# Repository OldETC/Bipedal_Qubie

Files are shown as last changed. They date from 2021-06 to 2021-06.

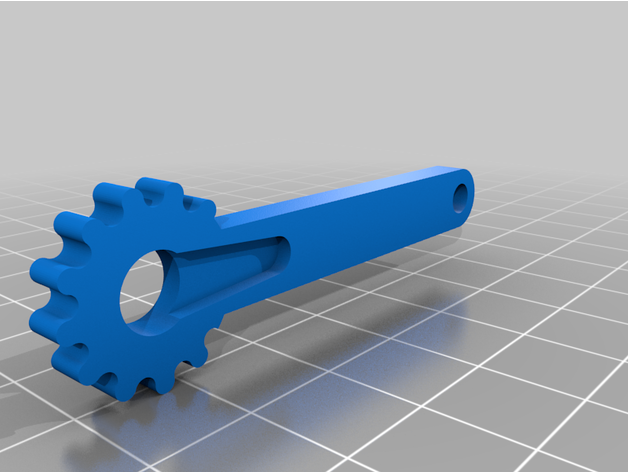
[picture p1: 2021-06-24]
PrintDesign/minigripper/minigripper/images/Servo_Connector_Gear.png

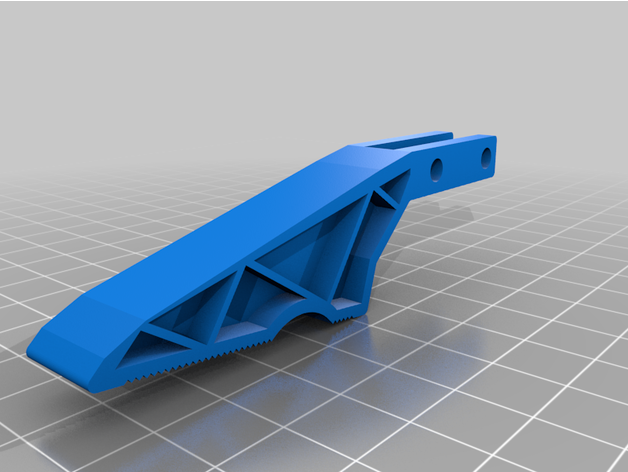
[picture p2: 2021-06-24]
PrintDesign/minigripper/temp/images/Claw.png

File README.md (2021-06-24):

# Bipedal_Qubie

20200904_standing

Prototype small (40" tall) humanoid robot
This robot is just for personal use, not commercial.  It is built from readily available hobby
electronics, hobby servos and the skeleton is 3D printed.  I have been working on it for quite a
while, but not accomplished much other than to get the basic robot built and standing on its
own.  I have gotten the  gazebo model complete, but not debugged or the driver code written yet.

The file include documentation for the electronics used, the servos, the OpenSCAD files for the skeleton, some documentation, and a bit of the test code for the robot.

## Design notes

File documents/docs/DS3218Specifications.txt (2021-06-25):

DS3218 specifications:
DS3218MG Servo can be commonly used in robots, mechanical arms, climbing cars and remote control toys. The main features are fast heat dissipation, big torque high compatibility, sensitive and responsive ect. Good choice for university professors and students who are interested in developing software for robot parts.

Features:
Wide operating voltage-4.8V to 6.8V
High-precision metal gears with hard anodizing 
High sensitivity and responsiveness, flexible operation
CNC aluminium and plastic shell, waterproof rubber seals screws 
Perfectly for robots, mechanical arms, climbing cars and remote control toys

Specifications:
Brand: DSSERVO
Model: DS3218MG
Item Name: DS3218MG Digital Servo
Dead Band: 3μsec
Operating Voltage: 4.8V~6.8Volts 
Operating Speed (5V): 0.16sec / 60° at no load
Operating Speed (6.8V): 0.14sec / 60° at no load
Stall Torque (5V): 19 kg/cm (263.8oz/in)
Stall Torque (6.8V): 21.5 kg/cm (298.5 oz/in)
Motor Type: DC Motor
Gear Type: Copper & Aluminum
Working Frequency: 1520μs / 333hz
CE Certification: Yes
Weight: 60g
Size: 40.5 * 40 * 20mm

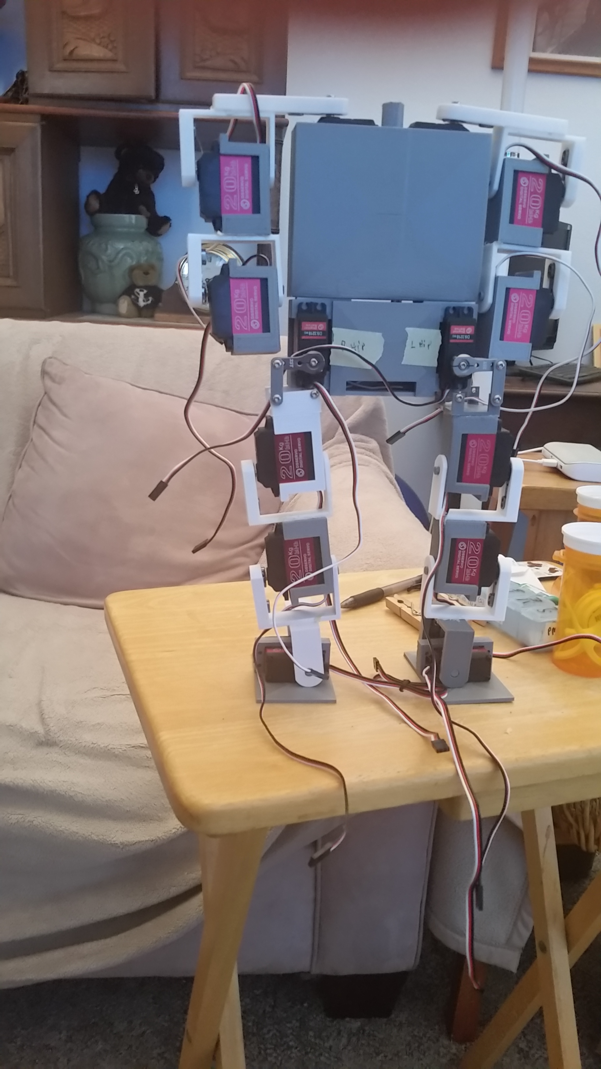
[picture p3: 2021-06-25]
photos/20200207_almost.jpg

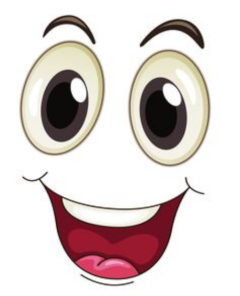
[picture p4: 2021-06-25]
Qubie_code/python/face.jpg

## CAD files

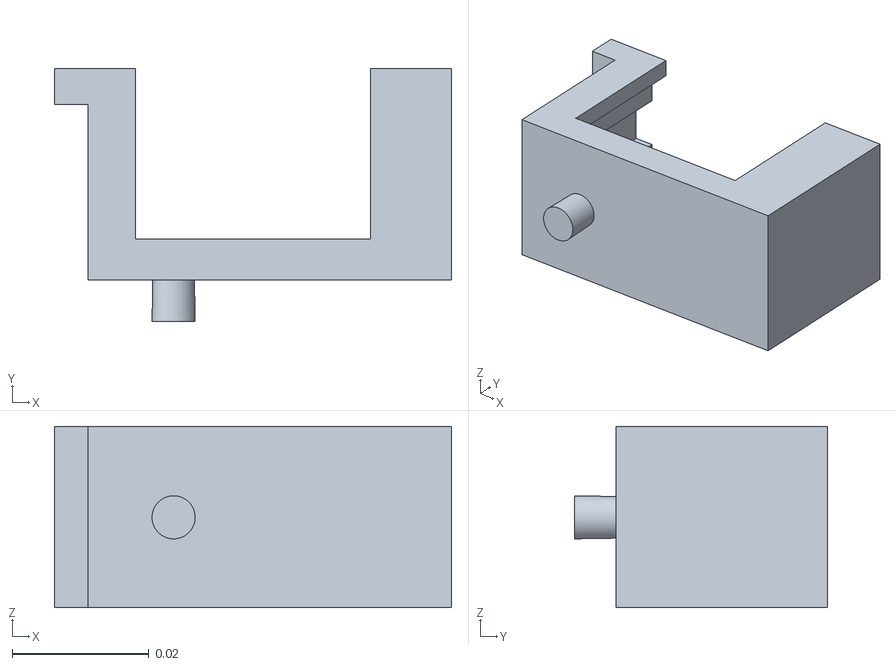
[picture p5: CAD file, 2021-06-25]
qubie/stl/mainservobracket.stl
0.058 x 0.0369 x 0.0265

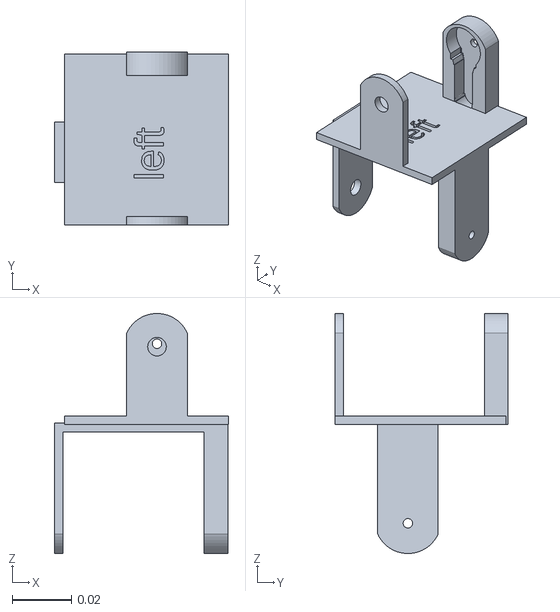
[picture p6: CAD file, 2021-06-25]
qubie/stl/gazeboLefthiptiltassy.stl
0.059 x 0.0587 x 0.0812

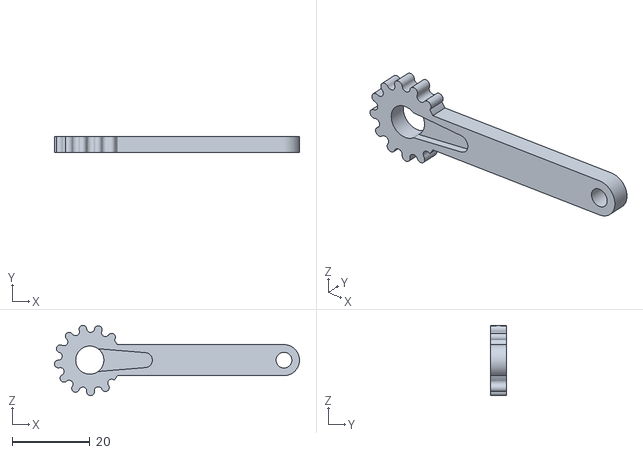
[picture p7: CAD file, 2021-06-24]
PrintDesign/minigripper/minigripper/files/Servo_Connector_Gear.stl
63.1 x 4.00 x 18.1

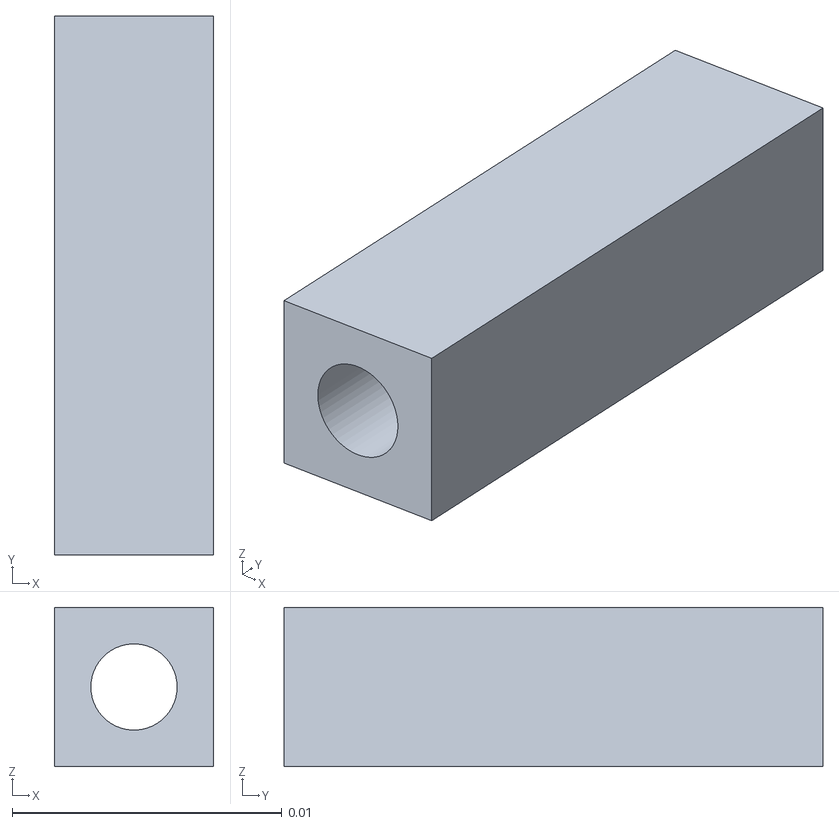
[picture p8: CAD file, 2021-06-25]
qubie/stl/head/headtiltspacer.stl
0.0059 x 0.02 x 0.0059

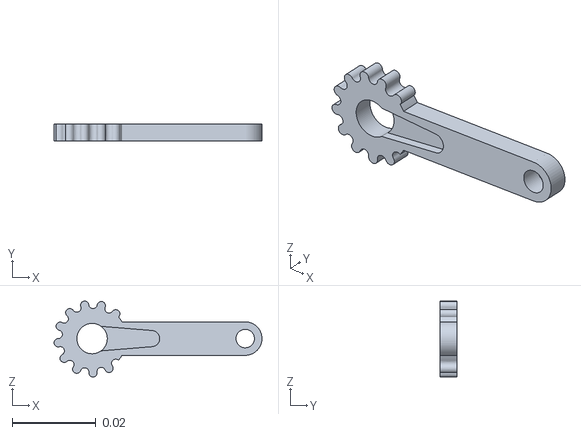
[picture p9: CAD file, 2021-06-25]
qubie/stl/microgripper/ServoConGear.stl
0.0496 x 0.004 x 0.0181

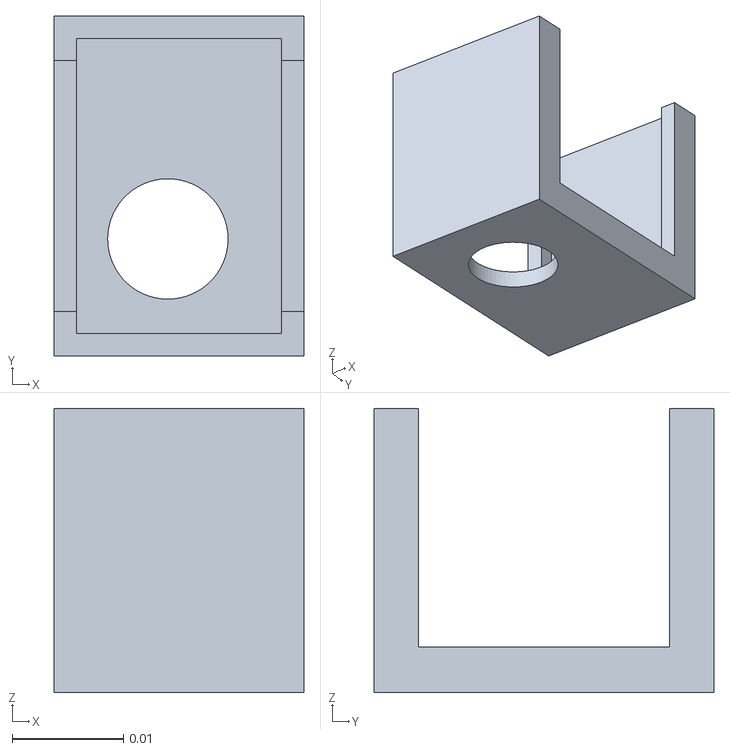
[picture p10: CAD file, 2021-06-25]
qubie/stl/minigripper/servowristcover.stl
0.0224 x 0.0305 x 0.0255

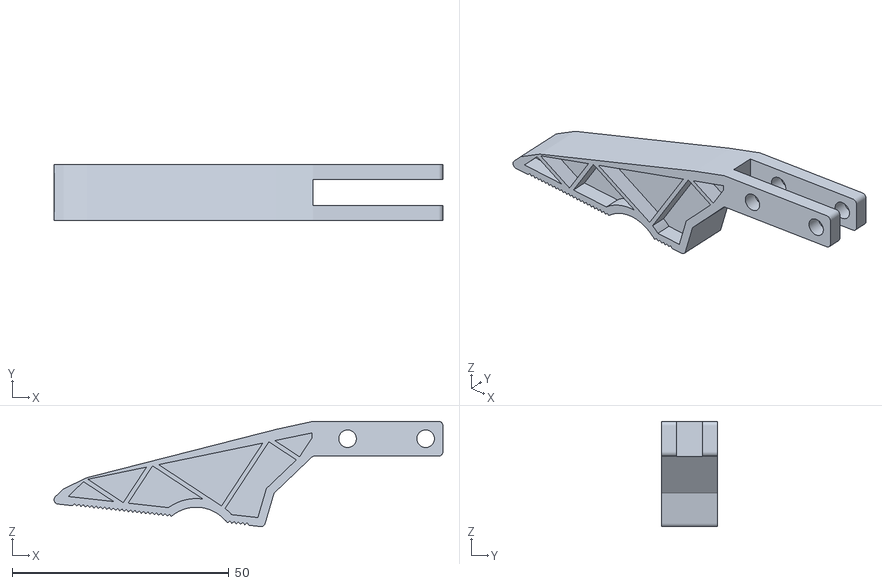
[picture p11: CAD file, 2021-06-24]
PrintDesign/minigripper/minigripper/files/Claw.stl
89.7 x 12.9 x 24.3

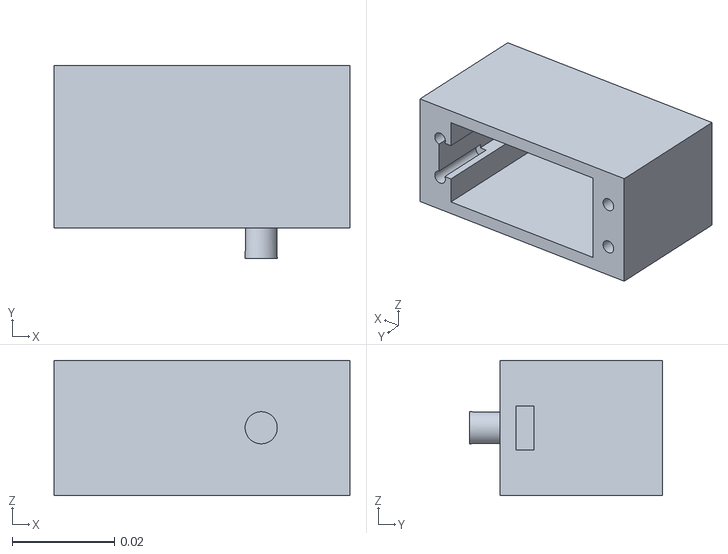
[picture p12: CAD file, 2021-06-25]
qubie/stl/footassembly/Fservobox.stl
0.058 x 0.0379 x 0.0265

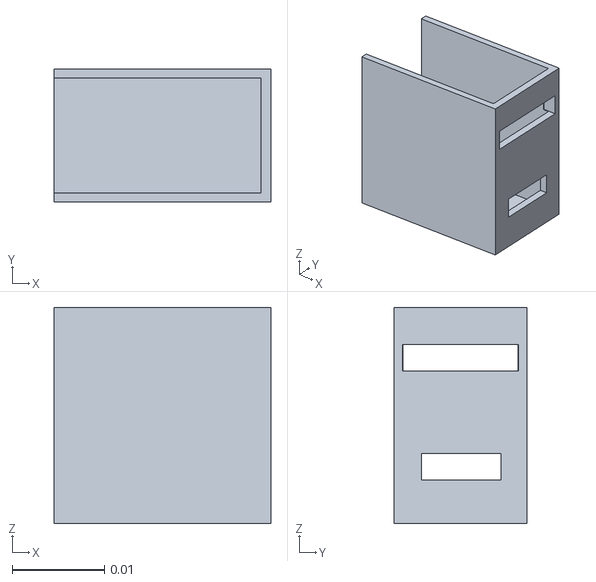
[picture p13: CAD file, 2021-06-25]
qubie/stl/head/servobox.stl
0.0235 x 0.0144 x 0.0234

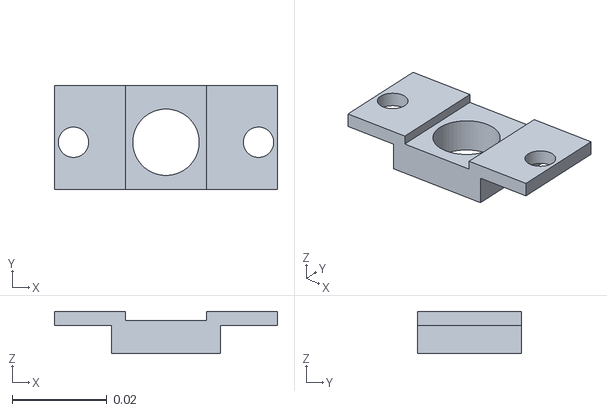
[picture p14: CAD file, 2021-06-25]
qubie/stl/improvedShoulder.stl
0.047 x 0.022 x 0.0089

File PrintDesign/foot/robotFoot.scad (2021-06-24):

// robotFoot
/* 

Copyright 2020 Howard L. Howell (Les)

Licensed under the Apache License, Version 2.0 (the "License");
you may not use this file except in compliance with the License.
You may obtain a copy of the License at

http://www.apache.org/licenses/LICENSE-2.0

Unless required by applicable law or agreed to in writing, software
distributed under the License is distributed on an "AS IS" BASIS,
WITHOUT WARRANTIES OR CONDITIONS OF ANY KIND, either express or implied.
See the License for the specific language governing permissions and
limitations under the License.
*/
/************************************************************
 ** created 2020 HLH
 ** from existing code in mybiped
 ** to add another degree of freedom.
 ***********************************************************/

include </home/lesh/3dprint_things/mybiped/PrintDesign/DS3218mglib.scad>


module dummyservo(){
    // a simulation of the servo body used to check component
    // fit and proportions. 
    union(){
        cube([servolength(),servoheight(), servowidth()]);
        translate([shaftlocationL(),servoheight()+5.9,servowidth()/2])
            rotate([90,0,0])
                cylinder(6,servoshaftdia()/2,servoshaftdia()/2,$fn=60);
        translate([-mountingtabdepth()-.1,mountingtablocation(),0])
            cube([mountingtabdepth(),mountingtabthick(),servowidth()]);
        translate([servolength()-.1,mountingtablocation(),0])
            cube([mountingtabdepth(),mountingtabthick(),servowidth()]);
    }
}

module footservobracket(){
    difference(){
        cube([servolength()+mountingtabdepth()+6,10,servowidth()+6.1]);
        translate([7,-1,-.1])
            cube([servolength(),12,servowidth()+3.1]);
        translate([servolength()+connthick()+3,-.1,servowidth()/2-connwidth()/2+4])
            cube([connthick()+1,12,connwidth()-1]);
        translate([6-2.3,12,6+2.3])
            rotate([90,0,0]) color("red")
                cylinder(21,1.5,1.5,$fn=50);
        translate([6-2.3,12,servowidth()-2.3])
            rotate([90,0,0]) color("red")
                cylinder(21,1.5,1.5,$fn=50);
        translate([servolength()+7.8+2.3,12,6+2.3])
            rotate([90,0,0]) color("red")
                cylinder(21,1.5,1.5,$fn=50);
        translate([servolength()+7.8+2.3,12,servowidth()-1.3])
            rotate([90,0,0]) color("red")
                cylinder(21,1.5,1.5,$fn=50);
    }
}

module pivottrim(){
    // used to get a curve on the ends of pivotingBrackets
    difference(){
        cube([servowidth()+2,2*servoheight()+5,(servowidth()+5)]);
        translate([(servowidth()+2)/2,0,0])
            rotate([-90,0,0])
                cylinder(2*servoheight()+10, (servowidth()+2)/2, 
                         (servowidth()+2)/2,$fn=50);
    }
}
module armsim(){
    // used to simulate the arm to make the arm opening
    // in the various pieces that need it.  Note that the 
    // slope of the shoulder to the clamp circle is independent
    // of any measurement.  You have to use armfit to verify that
    // any change in the arm works correctly.  You achieve this by 
    // changing the rotation angle and size of the cubes, or by 
    // changing the size and position of the block to allow the
    // screw clearance at the axel clamps.
    union(){
        cylinder(armThickness(),
                 armPivotWidth()/2+.2,
                 armPivotWidth()/2+.2,$fn=100);
        // use two cubes to add the taper on the arm at the pivot end
        color("red")
        translate([armPivotWidth()/2*sin(10/armPivotWidth()/2)-5,
                    armPivotWidth()/2-1,0])
            rotate([0,0,-15])
                cube([3,3,armThickness()]);
        // this is the second one.
        color("red")
        translate([armPivotWidth()/2*sin(10/armPivotWidth()/2)+3,
                    armPivotWidth()/2-3,0])
            rotate([0,0,15])
                cube([3,4,armThickness()]);
        // the actual arm part length is +1mm to provide fitment space
        translate([-armSmallWidth()/2+.2,0,0])
            cube([armSmallWidth()+.4,
                  armOverAllLength()-armPivotWidth()/2-armSmallWidth()/2+1,
                  armThickness()]);
        translate([.4,armOverAllLength()-(armPivotWidth()/2)-armSmallWidth()/2+1,0])
            cylinder(armThickness(),(armSmallWidth()+.2)/2,(armSmallWidth()/2)+.2,$fn=100);
        // bolt offsets.  The metal arm has two tension bolts that have to pass into
        // the relief for the arm.
         translate([-armTensionBoltLength()/2,armPivotWidth()/2-4,0])
            color("green")
            cube([armTensionBoltLength()+1, armTensionBoltDia(),armThickness()]);
        
    }
}
module pivotingBracket(){
// fastens to servo horn and fits over the pin on the main bracket to pivot.
    // The depth has to exceed the pivot point by:
    //      mountingtabdepth()+.707*servowidth()+1mm 
    // for clearance when pivoting.
    armthick=bracketthickness()+armThickness();
    clearance=shaftlocationL()+.707*servowidth()+mountingtabdepth()+1;
    pivotdepth=servoheight()+servocollarthick()+2*bracketthickness()+mountingtabdepth();    
    difference(){
        echo ("armthick=",armthick);
        cube([clearance+bracketthickness()+10, 
             servoheight()+2*armthick,
             servowidth()]); // bracket size
        translate([clearance,-5,servowidth()+1])
            rotate([0,90,0])
                pivottrim(); // put the round trim on it.
        translate([bracketthickness(),bracketthickness(),-.1])
            cube([clearance+bracketthickness()+7,
                  servoheight()+servocollarthick()+2*bracketthickness(),
                  servowidth()+1]); // make it a shell
        translate([clearance,-10,servowidth()/2])
            rotate([-90,0,0])
                cylinder(30,
                         servoshaftdia()/2+.1,
                         servoshaftdia()/2+.1,$fn=50); // add the pivot hole opposite the servo shaft.
         if(useArm()){// if a high power servo, use the metal arm
            color("red")
            translate([armOverAllLength(),
                 servoheight()+servocollarthick()+armthick+armThickness()-.1,
                 servowidth()/2])
               rotate([90,-90,0])
                armsim(); // subtract the simulation of the arm from the bracket
            translate([clearance+1,servoheight(),servowidth()/2])
                rotate([0,90,90])
                    color("gray")
                    cylinder(20,1.6,1.6,$fn=50); // add the screw hole for attaching to servo
        }
        else {
            translate([clearance,servoheight()+5*bracketthickness(),servowidth()/2])
                rotate([90,0,0])
                    splineshaft();
        }
    }
}
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

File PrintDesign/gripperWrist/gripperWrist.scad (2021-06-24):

// gripperWrist.scad
/******************************************************
  A gripper designed for mybiped prototype humanoid robot
  it rotates and has a pincer type grip.
********************************************************/
/***********************************************
  materials:
    3d prints of these parts
    3mm screws and nuts
    2 mini sg90 servos (may be different but affects design)
    some silicon sealant to improve the grip.
    some glue for your chosen plastic.
*******************************************************/
include </home/lesh/3dprint_things/mybiped/PrintDesign/SG90lib.scad>
// a shell thickness to use
shell=1.0; 
module servoMount(){
    // a box to hold a servo as described in the library.
    difference(){
        cube([SG90servowidth()+2*shell,
            SG90servolength()+2*shell,
            SG90mountingtablocation()+shell]);
        translate([1,1,1.1]){
            cube([SG90servowidth(),
                  SG90servolength(),
                  SG90mountingtablocation()+shell]);
        translate([-2,3,3])
        cube([SG90servowidth()+4*shell,
            SG90servolength()-6,
            SG90mountingtablocation()+shell]);
        translate([(SG90servowidth()+2*shell)/2-cablewidth()/2,-2,cableheight()])
            cube([cablewidth(),3,SG90servoheight()]);
        }
    }
}

module dualServoMount(){
    union(){
        servoMount();
        translate([SG90servowidth()+1.95*shell,
                   SG90servoheight()+1.95*shell,0]){
            rotate([90,0,0]){
                servoMount();
            }
        }
    }
}
module armtemplate(){
    union(){
        cylinder(1.5,3.75,3.75,$fn=50);
        linear_extrude(height=2.5)
        polygon(points= [[-3.5,0],
                        [-3.1,7.9],
                        [3.1,7.9],
                        [3.5,0],
                        [3.1,-7.9],
                        [-3.1,-7.9],
                        [-3.5,0]]);
    }
}

module pivotplate(){
    difference(){
        union(){
            cylinder(4,7.8,7.88,$fn=50);
            cylinder(8.2,3,3,$fn=50);
        }
        translate([0,0,-.1])
            armtemplate();
        }
}
module pivotplatecap(){
    difference(){
        cylinder(2,7.8,7.8,$fn=50);
        translate([0,0,-1])
            cylinder(4,3.75,3.75,$fn=50);
    }
}

module pivotcap(){
    difference(){
        union(){
            cylinder(2,7.8,7.8,$fn=50);
            cylinder(4.2,5.1,5.1,$fn=50);
        }
        translate([0,0,-1])
            cylinder(6,3.2,3.2,$fn=50);
    }
}

module pivotcheck(){
    difference(){
        translate([-15,-10,0])
            cube([30,20,2]);
        translate([0,0,-1])
            cylinder(4,5.4,5.4,$fn=60);
    }
}

//servoMount();
//armtemplate();

//dualServoMount();
pivotplate();
// pivotplatecap();
//translate([0,0,4.2])
//    rotate([0,180,0])
//        color("red")
//        pivotcap();
//pivotcheck();
//pivotcap();

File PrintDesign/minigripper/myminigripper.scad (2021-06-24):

// myminigrip.scad
/*****************************************************
 ** based on the minigripper in thingiverse:
 ** https://www.thingiverse.com/thing:4243097
 ** This thing was created by Thingiverse user Alarik72,
 ** and is licensed under cc-nc-sa.
 ** reduced in size with new claw design which will
 ** take silicon pads pasted onto them.
 ** shrunk about 1/3 in size to match my robot.
 *****************************************************/
include </home/lesh/3dprint_things/mybiped/PrintDesign/SG90lib.scad>
shell=2;
module claw(){
    difference(){
        scale([.75,.6,.6]){
            union(){
                import("./temp/files/Claw.stl",convexity=7);
                translate([-29,0,-5])
                    cube([30,3.5,10]);
                translate([-29,9.3,-5])
                    cube([30,3.5,10]);
            }
        }
        translate([-3,9,0])
            rotate([90,0,0])
                cylinder(10,2.1,2.1,$fn=50);
        translate([-18,9,0])
            rotate([90,0,0])
                cylinder(10,2.1,2.1,$fn=50);    }
}
module fullbase(){
    union(){
        difference(){
            union(){
                import("./temp/files/Base_AR2.stl",convexity=20);
                // eliminate the original screw holes
                translate([-18,0,-10])
                    cube([6,13,6]);
                translate([-18,0,4])
                    cube([6,13,6]);
            }
            // truncate the front edge
           translate([-21,-1,-20])
                cube([5,15,60]);
            // truncate the back
            translate([30,-1,-30])
                cube([35,35,60]);
            // add the screw holes for the claw arms
            translate([-12,15,4.2])
                rotate([90,0,0])
                    color("red")
                    cylinder(18,2.2,2.2,$fn=50);
            translate([-12,15,-4.2])
                rotate([90,0,0])
                    color("red")
                    cylinder(18,2.2,2.2,$fn=50);
        }
        // wrist lower support wall
        translate([29,0,-22])
            cube([3,13,12.3]);
        // wrist base support
        translate([29,0,-10])
            cube([14.5,2,5]);
        // writes upper support wall
        translate([29,0,16]) 
            cube([3,13,6]);
        // wrist base support
        translate([29,0,11.5]) 
            cube([14.5,2,5]);
        // box for wrist servo
        translate([25,1,-10])
            rotate([90,0,90])
                servoMount();
    }
}
module servoConGear(){
    difference(){
        union(){
            difference(){
                import("./temp/files/Servo_Connector_Gear.stl",convexity=20);
                translate([24.5,-3,-5])
                    cube([100,10,10]);
            }
            translate([24.5,2,0])
                rotate([90,0,0])
                    cylinder(4,4,4,$fn=50);
        }
        translate([24.5,3,0])
            rotate([90,0,0])
                cylinder(6,2.2,2.2,$fn=50);
    }
}
module ConGear(){
    difference(){
        union(){
            difference(){
                import("./temp/files/Connector_Gear.stl",convexity=20);
                translate([24.5,-3,-5])
                    cube([100,10,10]);
            }
            translate([24.5,2,0])
                rotate([90,0,0])
                    cylinder(4,4,4,$fn=50);
        }
        translate([24.5,3,-.75])
            rotate([90,0,0])
                cylinder(6,2.1,2.2,$fn=50);
    }
}
module connector(){
    difference(){
        union(){
            cube([7.8,34.4,3.5]);
            translate([3.9,0,0])
                cylinder(3.5,3.9,3.9,$fn=50);
            translate([3.9,34.4,0])
                cylinder(3.5,3.9,3.9,$fn=50);
        }
        translate([3.9,0,-1])
            cylinder(5,2.1,2.1,$fn=50);
        translate([3.9,34.4,-1])
            cylinder(5,2.1,2.1,$fn=50);
    }
}
module siliconrecess(){
    union(){
        cylinder(3,1.3,1.3,$fn=50);
        translate([0,0,3])
            sphere(2,$fn=50);
    }
}
module myclaw(){
    difference(){
        union(){
            translate([0,-3,0])
                cube([25,10,10]);
            translate([19,-2,0])
                rotate([0,0,-25])
                    cube([40,17,10]);
        }
        // split for connectors
        translate([-1,-4,3.2])
            cube([27,23,3.6]);
        // holes for connector screws
        translate([4,2,-1])
            cylinder(20,2.1,2.1,$fn=50);
        translate([19.3,2,-1])
            cylinder(20,2.1,2.1,$fn=50);
        //
        translate([0,4,0]){
            // shape the gripper angle
            translate([19,-27,-1])
                cube([50,20,12]);
            // sharpen the nose a bit
                translate([66,-15,-1])
                rotate([0,0,45])
                    cube([10,10,12]);
            //lighten it with holes
            translate([53.5,-5,-1])
                cylinder(15,1,1,$fn=50);
            translate([47.5,-4.5,-1])
                cylinder(15,1.5,1.5,$fn=50);
            translate([40,-3.5,-1])
                cylinder(15,2,2,$fn=50);
            translate([30,0,-1])
                cylinder(15,4.5,4.5,$fn=50);
            translate([45,4,-1])
                rotate([0,0,-15])
                scale([1.1,.9,1])
                    cylinder(15,6,6,$fn=50);
        }
        translate([58,-2.5,-1]) color("red")
            cube([1,1,12]);
        translate([55,-1,-1]) color("red")
            cube([1,1,12]);
        translate([52,0.5,-1]) color("red")
            cube([1,1,12]);        
        translate([49,2,-1]) color("red")
            cube([1,1,12]);
        translate([46,2,-1]) color("red")
            cube([1,1,12]);
        translate([43,2.2,-1]) color("red")
            cube([1,1,12]);
        translate([40.5,3.4,-1]) color("red")
            cube([1,1,12]);
        translate([39,5.2,-1]) color("red")
            cube([1,1,12]);
        translate([36,8,-1]) color("red")
            cube([1,1,12]);
        translate([34,9,-1]) color("red")
            cube([1,1,12]);
        translate([32,10,-1]) color("red")
            cube([1,1,12]);
        translate([30,10.7,-1]) color("red")
            cube([1,1,12]);
        translate([28,11.5,-1]) color("red")
            cube([1,1,12]);
    }
 }
module servoMount(){
    // a box to hold a servo as described in the library.
    difference(){
        cube([SG90servowidth()+2*shell,
            SG90servolength()+2*shell,
            SG90mountingtablocation()+shell]);
        //hole for the servo body
        translate([shell,shell,shell-.1]){
            cube([SG90servowidth(),
                  SG90servolength(),
                  SG90mountingtablocation()+shell]);
        // cuts down the sides 
        translate([-3,shell+1,shell-.1])
            cube([SG90servowidth()+4*shell,
                    SG90servolength()-6,
                    SG90mountingtablocation()+shell]);
        translate([(SG90servowidth()+2*shell)/2-cablewidth(),-shell-.1,cableheight()])
            cube([cablewidth(),3,SG90servoheight()]);
        }
    }
}
module servoWristCover(){
    difference(){
        cube([SG90servowidth()+4*shell+2,
            SG90servolength()+4*shell,
            SG90mountingtablocation()+shell+10]);
        translate([shell,shell,shell+.1]){
            cube([SG90servowidth()+2*shell+2,
                  SG90servolength()+2*shell,
                  SG90mountingtablocation()+2*shell+10]);
        }
        translate([-.1,2*shell,2*shell+.1]){
            cube([SG90servowidth()+5*shell+2,
                  SG90servolength(),
                  SG90mountingtablocation()+10]);
        }
        translate([(SG90servowidth()+4*shell)/2,
                    SG90shaftlocationL()+2*shell,-1])
            cylinder(4,5.4,5.4,$fn=60);
    }
}
module armtemplate(){
    union(){
        cylinder(2.5,3.75,3.75,$fn=50);
        linear_extrude(height=2.5)
        polygon(points= [[-3.4,0],
                        [-3.0,7.9],
                        [3.0,7.9],
                        [3.4,0],
                        [3.0,-7.9],
                        [-3.0,-7.9],
                        [-3.4,0]]);
    }
}

module pivotplate(){
    // mates to the servo horn
    difference(){
        union(){
            cylinder(4,7.8,7.88,$fn=50);
            cylinder(9.2,3,3,$fn=50);
        }
        translate([0,0,-.1])
            armtemplate();
        }
}
module pivotplatecap(){
    //glues to the arm
    // fits over the pivotplate
    difference(){
        cylinder(2,7.8,7.8,$fn=50);
        translate([0,0,-1])
            cylinder(4,3.75,3.75,$fn=50);
    }
}

module mountingPlate(){
    // holds the arm in the plate
    difference(){
        union(){
            cube([50,25,3]);
            translate([25,12.5,0])
                cylinder(3+shell+.2,5.1,4.9,$fn=50);
        }
        translate([25,12.5,-.1])
            cylinder(8,3.2,3.2,$fn=50);
    }
}
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

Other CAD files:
qubie/stl/gazeboRighthiptiltassy.stl
qubie/stl/hipassy/HipAssy.stl
qubie/stl/3218MainBracket.stl
qubie/stl/footassembly/robotShoe.stl
qubie/stl/hipassy/RightHipTilt.stl
PrintDesign/minigripper/temp/files/Connector_Gear.stl
qubie/stl/hipassy/hipmount.stl
PrintDesign/qubiegripper/qubiegripper.scad
GazeboSTLset/3218MainBracket.stl
GazeboSTLset/DS3218.stl
GazeboSTLset/ShoulderCrank.stl
GazeboSTLset/body.stl
GazeboSTLset/bodycover.stl
GazeboSTLset/footassembly/Fservobox.stl
GazeboSTLset/footassembly/Lfoot.stl
GazeboSTLset/footassembly/ankleServobox.stl
GazeboSTLset/footassembly/foot.stl
GazeboSTLset/footassembly/gazeboLeftAnkleTilt.stl
GazeboSTLset/footassembly/gazeboRighttAnkleTilt.stl
GazeboSTLset/footassembly/robotFoot.stl
GazeboSTLset/footassembly/robotShoe.stl
GazeboSTLset/footassembly/shoe.stl
GazeboSTLset/gazeboHead.stl
GazeboSTLset/gazeboLeftAnkleRoll.stl
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

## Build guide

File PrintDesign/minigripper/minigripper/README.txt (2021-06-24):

Robot Gripper 9g Micro Servo for AR2 or AR3 Robot by Alarik72 on Thingiverse: https://www.thingiverse.com/thing:4243097

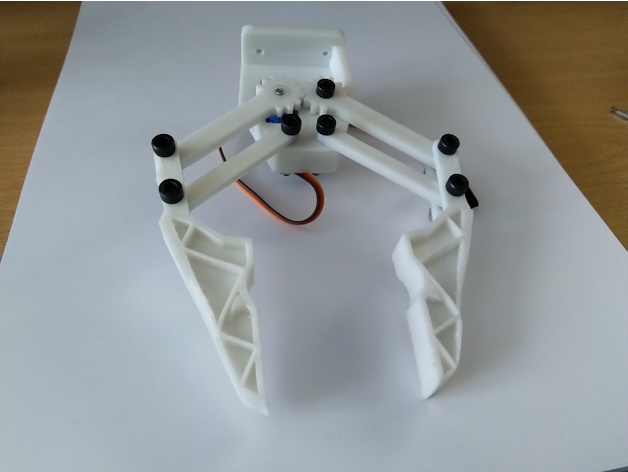
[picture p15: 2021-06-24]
PrintDesign/minigripper/minigripper/images/IMG_20200326_180722[1.jpg

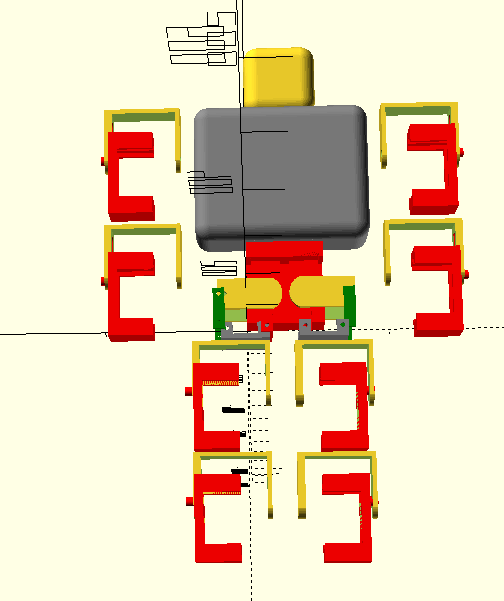
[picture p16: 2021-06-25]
photos/roughAssembly.png

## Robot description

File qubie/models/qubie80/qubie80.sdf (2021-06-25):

<?xml version='1.0'?>
<sdf version='1.7'>
  <model name='qubie80'>
    <link name='head'>
      <inertial>
        <mass>1</mass>
        <inertia>
          <ixx>0.166667</ixx>
          <ixy>0</ixy>
          <ixz>0</ixz>
          <iyy>0.166667</iyy>
          <iyz>0</iyz>
          <izz>0.166667</izz>
        </inertia>
        <pose>0 0 0 0 -0 0</pose>
      </inertial>
      <pose>0.039056 -0.068669 0.207528 0 -0 1.65656</pose>
      <self_collide>0</self_collide>
      <enable_wind>0</enable_wind>
      <kinematic>0</kinematic>
      <gravity>1</gravity>
      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
    </link>
    <link name='body'>
      <inertial>
        <mass>1</mass>
        <inertia>
          <ixx>0.166667</ixx>
          <ixy>0</ixy>
          <ixz>0</ixz>
          <iyy>0.166667</iyy>
          <iyz>0</iyz>
          <izz>0.166667</izz>
        </inertia>
        <pose>0 0 0 0 -0 0</pose>
      </inertial>
      <pose>-0.094503 -0.045689 0.171658 -1.571 0 0</pose>
      <self_collide>0</self_collide>
      <enable_wind>0</enable_wind>
      <kinematic>0</kinematic>
      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
      <sensor name='Vilma_IMU' type='imu'>
				<pose>0 0.000000 0.5 0.000000 -0.000000 0.000000</pose>
    		<imu>
      		<topic>__default_topic__</topic>
    		</imu>
    	<always_on>1</always_on>
    	<update_rate>30</update_rate>
    </sensor>
    </link>
    <link name='leftshin'>
      <inertial>
        <mass>1</mass>
        <inertia>
          <ixx>0.166667</ixx>
          <ixy>0</ixy>
          <ixz>0</ixz>
          <iyy>0.166667</iyy>
          <iyz>0</iyz>
          <izz>0.166667</izz>
        </inertia>
        <pose>0 0 0 0 -0 0</pose>
      </inertial>
      <pose>-0.119959 0.029387 -0.220722 0 -0 0</pose>
      <self_collide>0</self_collide>
      <enable_wind>0</enable_wind>
      <kinematic>0</kinematic>
      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
    </link>
    <link name='leftankle'>
      <inertial>
        <mass>1</mass>
        <inertia>
          <ixx>0.166667</ixx>
          <ixy>0</ixy>
          <ixz>0</ixz>
          <iyy>0.166667</iyy>
          <iyz>0</iyz>
          <izz>0.166667</izz>
        </inertia>
        <pose>0 0 0 0 -0 0</pose>
      </inertial>
      <pose>-0.030882 0.020479 -0.266064 0 0 -1.62404</pose>
      <self_collide>0</self_collide>
      <enable_wind>0</enable_wind>
      <kinematic>0</kinematic>
      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
    </link>
    <link name='rightshoulder'>
      <inertial>
        <mass>1</mass>
        <inertia>
          <ixx>0.166667</ixx>
          <ixy>0</ixy>
          <ixz>0</ixz>
          <iyy>0.166667</iyy>
          <iyz>0</iyz>
          <izz>0.166667</izz>
        </inertia>
        <pose>0 0 0 0 -0 0</pose>
      </inertial>
      <pose>0.055501 -0.032019 0.172838 0 -0 1.57101</pose>
      <self_collide>0</self_collide>
      <enable_wind>0</enable_wind>
      <kinematic>0</kinematic>
      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
    </link>
    <link name='rightbicep'>
      <inertial>
        <mass>1</mass>
        <inertia>
          <ixx>0.166667</ixx>
          <ixy>0</ixy>
          <ixz>0</ixz>
          <iyy>0.166667</iyy>
          <iyz>0</iyz>
          <izz>0.166667</izz>
        </inertia>
        <pose>0 0 0 0 -0 0</pose>
      </inertial>
      <pose>0.132495 0.018032 0.200246 3e-06 1.55283 -1.58218</pose>
      <self_collide>0</self_collide>
      <enable_wind>0</enable_wind>
      <kinematic>0</kinematic>
      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
    </link>
    <link name='rightwristflex'>
      <inertial>
        <mass>1</mass>
        <inertia>
          <ixx>0.166667</ixx>
          <ixy>0</ixy>
          <ixz>0</ixz>
          <iyy>0.166667</iyy>
          <iyz>0</iyz>
          <izz>0.166667</izz>
        </inertia>
      </inertial>
      <pose>0.172162 0.012361 0.04169 3.14159 1.56849 -0.009426</pose>
      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
    </link>
    <link name='righthip'>
      <inertial>
        <mass>1</mass>
        <inertia>
          <ixx>0.166667</ixx>
          <ixy>0</ixy>
          <ixz>0</ixz>
          <iyy>0.166667</iyy>
          <iyz>0</iyz>
          <izz>0.166667</izz>
        </inertia>
        <pose>0 0 0 0 -0 0</pose>
      </inertial>
      <pose>0.043677 -0.018584 -0.024693 -1.56111 -1.56814 -5e-06</pose>
      <gravity>1</gravity>
      <self_collide>0</self_collide>
      <kinematic>0</kinematic>
      <enable_wind>0</enable_wind>
      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
    </link>
    <link name='rightshin'>
      <inertial>
        <mass>1</mass>
        <inertia>
          <ixx>0.166667</ixx>
          <ixy>0</ixy>
          <ixz>0</ixz>
          <iyy>0.166667</iyy>
          <iyz>0</iyz>
          <izz>0.166667</izz>
        </inertia>
        <pose>0 0 0 0 -0 0</pose>
      </inertial>
      <pose>0.105894 0.032786 -0.222578 0 0 -3.13986</pose>
      <self_collide>0</self_collide>
      <enable_wind>0</enable_wind>
      <kinematic>0</kinematic>
      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
    </link>
    <link name='rightankle'>
      <inertial>
        <mass>1</mass>
        <inertia>
          <ixx>0.166667</ixx>
          <ixy>0</ixy>
          <ixz>0</ixz>
          <iyy>0.166667</iyy>
          <iyz>0</iyz>
          <izz>0.166667</izz>
        </inertia>
        <pose>0 0 0 0 -0 0</pose>
      </inertial>
      <pose>0.019389 0.030533 -0.269881 0 0 -1.59633</pose>
      <self_collide>0</self_collide>
      <enable_wind>0</enable_wind>
      <kinematic>0</kinematic>
      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
    </link>
    <link name='leftshoulder'>
      <inertial>
        <mass>1</mass>
        <inertia>
          <ixx>0.166667</ixx>
          <ixy>0</ixy>
          <ixz>0</ixz>
          <iyy>0.166667</iyy>
          <iyz>0</iyz>
          <izz>0.166667</izz>
        </inertia>
        <pose>0 0 0 0 -0 0</pose>
      </inertial>
      <pose>-0.066798 -0.033458 0.174646 0 -0 1.55819</pose>
      <self_collide>0</self_collide>
      <enable_wind>0</enable_wind>
      <kinematic>0</kinematic>
      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
    </link>
    <link name='rightforearm'>
      <inertial>
        <mass>1</mass>
        <inertia>
          <ixx>0.166667</ixx>
          <ixy>0</ixy>
          <ixz>0</ixz>
          <iyy>0.166667</iyy>
          <iyz>0</iyz>
          <izz>0.166667</izz>
        </inertia>
        <pose>0 0 0 0 -0 0</pose>
      </inertial>
      <pose>0.131774 0.018782 0.126405 -3e-06 1.55057 -1.56845</pose>
      <self_collide>0</self_collide>
      <enable_wind>0</enable_wind>
      <kinematic>0</kinematic>
      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
    </link>
    <link name='leftbicep'>
      <inertial>
        <mass>1</mass>
        <inertia>
          <ixx>0.166667</ixx>
          <ixy>0</ixy>
          <ixz>0</ixz>
          <iyy>0.166667</iyy>
          <iyz>0</iyz>
          <izz>0.166667</izz>
        </inertia>
      </inertial>
      <pose>-0.145019 -0.006374 0.202348 1.61458 1.54947 3.13189</pose>
      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
    </link>
    <link name='lefthip'>
      <inertial>
        <mass>1</mass>
        <inertia>
          <ixx>0.166667</ixx>
          <ixy>0</ixy>
          <ixz>0</ixz>
          <iyy>0.166667</iyy>
          <iyz>0</iyz>
          <izz>0.166667</izz>
        </inertia>
        <pose>0 0 0 0 -0 0</pose>
      </inertial>
      <pose>-0.053316 0.001213 -0.024658 -1.62568 -1.56909 -3.14158</pose>
      <self_collide>0</self_collide>
      <enable_wind>0</enable_wind>
      <kinematic>0</kinematic>
      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
    </link>
    <link name='rightfoot'>
      <inertial>
        <mass>1</mass>
        <inertia>
          <ixx>0.166667</ixx>
          <ixy>0</ixy>
          <ixz>0</ixz>
          <iyy>0.166667</iyy>
          <iyz>0</iyz>
          <izz>0.166667</izz>
        </inertia>
        <pose>0 0 0 0 -0 0</pose>
      </inertial>
      <pose>0.094329 -0.044865 -0.271475 0.014031 -0.009614 1.58855</pose>
      <self_collide>0</self_collide>
      <enable_wind>0</enable_wind>
      <kinematic>0</kinematic>
      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
    </link>
    <link name='leftforearm'>
      <inertial>
        <mass>1</mass>
        <inertia>
          <ixx>0.166667</ixx>
          <ixy>0</ixy>
          <ixz>0</ixz>
          <iyy>0.166667</iyy>
          <iyz>0</iyz>
          <izz>0.166667</izz>
        </inertia>
      </inertial>
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

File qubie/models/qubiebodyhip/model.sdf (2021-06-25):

<?xml version='1.0'?>
<sdf version='1.7'>
  <model name='qubiebodyhip'>
    <link name='link_0'>
      <inertial>
        <mass>1</mass>
        <inertia>
          <ixx>0.166667</ixx>
          <ixy>0</ixy>
          <ixz>0</ixz>
          <iyy>0.166667</iyy>
          <iyz>0</iyz>
          <izz>0.166667</izz>
        </inertia>
      </inertial>
      <pose>-0.075524 0.002272 0.149146 -1.56143 0 0</pose>
      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
    </link>
    <link name='link_1'>
      <inertial>
        <mass>1</mass>
        <inertia>
          <ixx>0.166667</ixx>
          <ixy>0</ixy>
          <ixz>0</ixz>
          <iyy>0.166667</iyy>
          <iyz>0</iyz>
          <izz>0.166667</izz>
        </inertia>
      </inertial>
      <pose>0.035938 0.002685 -0.048866 1.57499 7e-06 3.13991</pose>
      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
    </link>
    <link name='link_2'>
      <inertial>
        <mass>1</mass>
        <inertia>
          <ixx>0.166667</ixx>
          <ixy>0</ixy>
          <ixz>0</ixz>
          <iyy>0.166667</iyy>
          <iyz>0</iyz>
          <izz>0.166667</izz>
        </inertia>
      </inertial>
      <pose>0.081504 -0.00476 -0.050066 0 -0 1.59857</pose>
      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
    </link>
    <link name='link_2_clone'>
      <inertial>
        <mass>1</mass>
        <inertia>
          <ixx>0.166667</ixx>
          <ixy>0</ixy>
          <ixz>0</ixz>
          <iyy>0.166667</iyy>
          <iyz>0</iyz>
          <izz>0.166667</izz>
        </inertia>
      </inertial>
      <pose>-0.055312 0.002839 -0.048867 0 -0 1.59857</pose>
      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
    </link>
    <joint name='link_0_JOINT_0' type='fixed'>
      <parent>link_0</parent>
      <child>link_1</child>
      <pose>0 0 0 0 -0 0</pose>
      <physics>
        <ode>
          <limit>
            <cfm>0</cfm>
            <erp>0.2</erp>
          </limit>
          <suspension>
            <cfm>0</cfm>
            <erp>0.2</erp>
          </suspension>
        </ode>
      </physics>
    </joint>
    <joint name='link_1_JOINT_1' type='revolute'>
      <parent>link_1</parent>
      <child>link_2</child>
      <pose>0 0.025 0.0625 0 -0 0</pose>
      <axis>
        <xyz>0 1 0</xyz>
        <limit>
          <lower>-1.79769e+308</lower>
          <upper>1.79769e+308</upper>
          <effort>-1</effort>
          <velocity>-1</velocity>
        </limit>
        <dynamics>
          <spring_reference>0</spring_reference>
          <spring_stiffness>0</spring_stiffness>
          <damping>0</damping>
        </dynamics>
      </axis>
      <physics>
        <ode>
          <limit>
            <cfm>0</cfm>
            <erp>0.2</erp>
          </limit>
          <suspension>
            <cfm>0</cfm>
            <erp>0.2</erp>
          </suspension>
        </ode>
      </physics>
    </joint>
    <joint name='link_1_JOINT_4' type='revolute'>
      <parent>link_1</parent>
      <child>link_2_clone</child>
      <pose>0 0 0 0 -0 0</pose>
      <axis>
        <xyz>1 0 0</xyz>
        <limit>
          <lower>-1.79769e+308</lower>
          <upper>1.79769e+308</upper>
          <effort>-1</effort>
          <velocity>-1</velocity>
        </limit>
        <dynamics>
          <spring_reference>0</spring_reference>
          <spring_stiffness>0</spring_stiffness>
          <damping>0</damping>
        </dynamics>
      </axis>
      <physics>
        <ode>
          <limit>
            <cfm>0</cfm>
            <erp>0.2</erp>
          </limit>
          <suspension>
            <cfm>0</cfm>
            <erp>0.2</erp>
          </suspension>
        </ode>
      </physics>
    </joint>
    <static>0</static>
    <allow_auto_disable>1</allow_auto_disable>
  </model>
</sdf>

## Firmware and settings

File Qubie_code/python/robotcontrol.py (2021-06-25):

""" RobotControl.py
    the joints are assigned to two servo driver boards
    They start at the top of the chest.  
    shoulder, bicep, elbow, wrist, claw, hip, thigh, knee, ankelroll anklepitch.
    The head nod and turn are in to top two slots for the right side.
"""
""" Apache license"""
"""
Copyright 2020 H. L. Howell

Licensed under the Apache License, Version 2.0 (the "License");
you may not use this file except in compliance with the License.
You may obtain a copy of the License at

    http://www.apache.org/licenses/LICENSE-2.0

Unless required by applicable law or agreed to in writing, software
distributed under the License is distributed on an "AS IS" BASIS,
WITHOUT WARRANTIES OR CONDITIONS OF ANY KIND, either express or implied.
See the License for the specific language governing permissions and
limitations under the License.
"""
import time
from adafruit_servokit import ServoKit
from board import SCL, SDA
import busio
from adafruit_pca9685 import PCA9685
from array import *
#import numpy as nmp

#the global parameters for controlling the joints.
shoulder=0
bicep=1
elbow=2
wrist=3
grip=4
hip=5
thigh=6
knee=7
ankleroll=8
anklepitch=9

LEFT=0x41
RIGHT=0x40

headnod=13
headturn=14

#setup for working ranges for servos in degrees enforced by hardware design
# follows the servo numbers used for the joints
ranges= [
# default  min  max minPW maxPW range     el# side designation
    [135,   105, 270, 500,  2500, 270], #  0 right shoulder
    [217,     9, 270, 500,  2500, 270], #  1 right bicep
    [135,     0, 270, 500,  2500, 270], #  2 right elbow
    [135,     0, 180, 500,  2500, 180], #  3 right wrist
    [ 33,    33, 100, 500,  2500, 180], #  4 right grip
    [135,   125, 144, 500,  2500, 270], #  5 right hip
    [135,   125, 144, 500,  2500, 270], #  6 right thigh
    [135,     0, 270, 500,  2500, 270], #  7 right knee
    [135,   125, 159, 500,  2500, 270], #  8 right foot roll
    [135,    92, 192, 500,  2500, 270], #  9 right foot pitch
    [  0,     0,   0,   0,     0,   0], # 10 reserved
    [  0,     0,   0,   0,     0,   0], # 11 reserved
    [  0,     0,   0,   0,     0,   0], # 12 reserved
    [ 90,     0, 180, 500,  2500, 180], # 13 head nod
    [ 90,     0, 180, 500,  2500, 180], # 14 head turn
    [  0,     0,   0,   0,     0,   0], # 15 reserved
    [135,   105, 270, 500,  2500, 270], # 16 left shoulder
    [217,     9, 270, 500,  2500, 270], # 17 left bicep
    [135,     0, 270, 500,  2500, 270], # 18 left elbow
    [135,     0, 180, 500,  2500, 180], # 19 left wrist
    [ 20,     0,  75, 500,  2500, 180], # 20 left grip
    [135,   125, 144, 500,  2500, 270], # 21 left hip
    [135,     0, 270, 500,  2500, 270], # 22 left thigh
    [135,     0, 270, 500,  2500, 270], # 23 left knee
    [135,   125, 159, 500,  2500, 270], # 24 left foot roll
    [135,    92, 192, 500,  2500, 270], # 25 left foot pitch
    [  0,     0,   0,   0,     0,   0], # 26 reserved
    [  0,     0,   0,   0,     0,   0], # 27 reserved
    [  0,     0,   0,   0,     0,   0], # 28 reserved
    [  0,     0,   0,   0,     0,   0], # 29 reserved
    [  0,     0,   0,   0,     0,   0], # 30 reserved
    [  0,     0,   0,   0,     0,   0], # 31 reserved
]

#creating the instances of the control software
# Set channels to the number of servo channels on your kit.
# 8 for FeatherWing, 16 for Shield/HAT/Bonnet.
# Set the PWM frequency to 200.
Left = ServoKit(channels=16,address=LEFT)
Right= ServoKit(channels=16,address=RIGHT)

def setup():

    Left.PWMfrequency=200
    j=0;
# setup the PCA code for the servo controlls.
    for i in range (0,15):
        Right.servo[i].set_pulse_width_range(ranges[j][3],ranges[j][4])
        Right.servo[i].actuation_range=ranges[j][5]
        Left.servo[i].set_pulse_width_range(ranges[j+16][3],ranges[j+16][4])
        Left.servo[i].actuation_range=ranges[j+16][5]
        j=j+1
#        print ('j=',j,'\n')

setup()
#right shoulder
#Right.servo[shoulder].angle=135


#print ('anklepitch=',anklepitch,anklepitch+16,'\n');
jnum=0
while 1:
    side=input('side:')
    if side=='q':
        break
    joint=input('joint:')
    if joint=='q':
       break
    elif joint=='shoulder':
        jnum=0
    elif joint=='bicep':
        jnum=1
    elif joint== 'elbow': 
        jnum=2
    elif joint=='wrist': 
        jnum=3
    elif joint=='grip': 
        jnum=4
    elif joint=='hip': 
        jnum=5
    elif joint=='thigh': 
        jnum=6
    elif joint=='knee': 
        jnum=7
    elif joint=='ankleroll': 
        jnum=8
    elif joint=='anklepitch': 
        jnum=9
        print("jnum:",jnum,"\n")
    elif joint=='nod':
        jnum=13
        side='right'
    elif joint =='turn':
        jnum=14
        side='right'
    else:
        break
    angle=input ('angle:')
    if angle=='q':
       break
    if side=='right':
        Right.servo[jnum].angle=int(angle)
        print ("moved Right\n")
    elif side=='left':
        Left.servo[jnum].angle=int(angle)
        print ("moved Left\n")
    print ("side:",side,"jnum:",jnum,"angle:",angle,"\n")

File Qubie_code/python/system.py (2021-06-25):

"""
This will show some Linux Statistics on the attached display. Be sure to adjust
to the display you have connected. Be sure to check the learn guides for more
usage information.
 
This example is for use on (Linux) computers that are using CPython with
Adafruit Blinka to support CircuitPython libraries. CircuitPython does
not support PIL/pillow (python imaging library)!
"""
 
import time
import subprocess
import digitalio
import board
from PIL import Image, ImageDraw, ImageFont
import adafruit_rgb_display.ili9341 as ili9341
import adafruit_rgb_display.st7789 as st7789  # pylint: disable=unused-import
import adafruit_rgb_display.hx8357 as hx8357  # pylint: disable=unused-import
import adafruit_rgb_display.st7735 as st7735  # pylint: disable=unused-import
import adafruit_rgb_display.ssd1351 as ssd1351  # pylint: disable=unused-import
import adafruit_rgb_display.ssd1331 as ssd1331  # pylint: disable=unused-import
 
# Configuration for CS and DC pins (these are PiTFT defaults):
cs_pin = digitalio.DigitalInOut(board.CE0)
dc_pin = digitalio.DigitalInOut(board.D25)
reset_pin = digitalio.DigitalInOut(board.D24)
 
# Config for display baudrate (default max is 24mhz):
BAUDRATE = 24000000
 
# Setup SPI bus using hardware SPI:
spi = board.SPI()
 
# pylint: disable=line-too-long
# Create the display:
# disp = st7789.ST7789(spi, rotation=90,                            # 2.0" ST7789
# disp = st7789.ST7789(spi, height=240, y_offset=80, rotation=180,  # 1.3", 1.54" ST7789
# disp = st7789.ST7789(spi, rotation=90, width=135, height=240, x_offset=53, y_offset=40, # 1.14" ST7789
# disp = hx8357.HX8357(spi, rotation=180,                           # 3.5" HX8357
# disp = st7735.ST7735R(spi, rotation=90,                           # 1.8" ST7735R
# disp = st7735.ST7735R(spi, rotation=270, height=128, x_offset=2, y_offset=3,   # 1.44" ST7735R
# disp = st7735.ST7735R(spi, rotation=90, bgr=True,                 # 0.96" MiniTFT ST7735R
# disp = ssd1351.SSD1351(spi, rotation=180,                         # 1.5" SSD1351
# disp = ssd1351.SSD1351(spi, height=96, y_offset=32, rotation=180, # 1.27" SSD1351
# disp = ssd1331.SSD1331(spi, rotation=180,                         # 0.96" SSD1331
disp = ili9341.ILI9341(
    spi,
    rotation=90,  # 2.2", 2.4", 2.8", 3.2" ILI9341
    cs=cs_pin,
    dc=dc_pin,
    rst=reset_pin,
    baudrate=BAUDRATE,
)
# pylint: enable=line-too-long
 
# Create blank image for drawing.
# Make sure to create image with mode 'RGB' for full color.
if disp.rotation % 180 == 90:
    height = disp.width  # we swap height/width to rotate it to landscape!
    width = disp.height
else:
    width = disp.width  # we swap height/width to rotate it to landscape!
    height = disp.height
 
image = Image.new("RGB", (width, height))
 
# Get drawing object to draw on image.
draw = ImageDraw.Draw(image)
 
# Draw a black filled box to clear the image.
draw.rectangle((0, 0, width, height), outline=0, fill=(0, 0, 0))
disp.image(image)
 
# First define some constants to allow easy positioning of text.
padding = -2
x = 0
 
# Load a TTF font.  Make sure the .ttf font file is in the
# same directory as the python script!
# Some other nice fonts to try: http://www.dafont.com/bitmap.php
font = ImageFont.truetype("/usr/share/fonts/truetype/dejavu/DejaVuSans.ttf", 24)
 
while True:
    # Draw a black filled box to clear the image.
    draw.rectangle((0, 0, width, height), outline=0, fill=0)
 
    # Shell scripts for system monitoring from here:
    # https://unix.stackexchange.com/questions/119126/command-to-display-memory-usage-disk-usage-and-cpu-load
    cmd = "hostname -I | cut -d' ' -f1"
    IP = "IP: " + subprocess.check_output(cmd, shell=True).decode("utf-8")
    cmd = "top -bn1 | grep load | awk '{printf \"CPU Load: %.2f\", $(NF-2)}'"
    CPU = subprocess.check_output(cmd, shell=True).decode("utf-8")
    cmd = "free -m | awk 'NR==2{printf \"Mem: %s/%s MB  %.2f%%\", $3,$2,$3*100/$2 }'"
    MemUsage = subprocess.check_output(cmd, shell=True).decode("utf-8")
    cmd = 'df -h | awk \'$NF=="/"{printf "Disk: %d/%d GB  %s", $3,$2,$5}\''
    Disk = subprocess.check_output(cmd, shell=True).decode("utf-8")
    cmd = "cat /sys/class/thermal/thermal_zone0/temp |  awk '{printf \"CPU Temp: %.1f C\", $(NF-0) / 1000}'"  # pylint: disable=line-too-long
    Temp = subprocess.check_output(cmd, shell=True).decode("utf-8")
 
    # Write four lines of text.
    y = padding
    draw.text((x, y), IP, font=font, fill="#FFFFFF")
    y += font.getsize(IP)[1]
    draw.text((x, y), CPU, font=font, fill="#FFFF00")
    y += font.getsize(CPU)[1]
    draw.text((x, y), MemUsage, font=font, fill="#00FF00")
    y += font.getsize(MemUsage)[1]
    draw.text((x, y), Disk, font=font, fill="#0000FF")
    y += font.getsize(Disk)[1]
    draw.text((x, y), Temp, font=font, fill="#FF00FF")
 
    # Display image.
    disp.image(image)
    time.sleep(0.1)

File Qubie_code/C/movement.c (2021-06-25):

// qubie.c
// a bipedal robot driver

/* 
Copyright 2020 Howard L. Howell (Les) (LesH)

Licensed under the Apache License, Version 2.0 (the "License");
you may not use this file except in compliance with the License.
You may obtain a copy of the License at

http://www.apache.org/licenses/LICENSE-2.0

Unless required by applicable law or agreed to in writing, software
distributed under the License is distributed on an "AS IS" BASIS,
WITHOUT WARRANTIES OR CONDITIONS OF ANY KIND, either express or implied.
See the License for the specific language governing permissions and
limitations under the License.
*/

/**********************************************
 **  Servo allocations
 *********************************************/
#define left 0    // the Left side of the body being referenced
#define right 16  // the right side of the body being referenced.
// left side servos
#define leftshoulder   0
#define lefttopjoint   1
#define leftelbow      2
#define leftwrist      3
#define leftgrip       4
#define leftpelvis     5
#define lefthip        6
#define leftknee       7
#define leftfootrot    8
#define leftfootpitch  9
#define reserved0     10
#define reserved1     11
#define reserved2     12
#define reserved3     13
#define nod           14
#define turn          15
// right side is on second servo driver
#define rightshoulder  16 
#define righttopjoint  17
#define rightelbow     18
#define rightwrist     19
#define rightgrip      20
#define rightpelvis    21
#define righthip       22
#define rightknee      23
#define rightfootrot   24
#define rightfootpitch 25
#define reserved4      26
#define reserved5      27
#define reserved6      28
#define reserved7      29
#define reserved6      30
#define reserved7      31


/*****************************************************************************************************
 ***  NOTE!!! All servo control and positions are set in microseconds.  Angles in degrees are calculated
 ***  based on liner interpolation from the min, zero and max conditions.
 *****************************************************************************************************/

float step_hip_tilt=16; // the number of degrees of hip tilt to get the body center over that foot.
float max_step_hip=20;  // the degree swing of the hip joint for a full step
int stepcount;          // the number of steps in a specific direction
int steptarget;         // the target for the current direction
float reldir;           // the direction relative to the origiinal pose
int currentstep=0;      // the move is either -1 for left step, 0 for stopped (default), 1 for right step
int nextstep=0;         // prediction used to help control acceleration and balance
float mapposition[3];   // where the robot's left foot is on the map.  
float currentpose[32];  // facing direction as 0,5 for each arm, 5 for each leg, 2 for the head position;

/********************************************************************************************************
 **  servo starting positions
 ********************************************************************************************************/
float startpose[32]={1500,1450,1560, 1200, 1200, // left shoulder, bicep, elbow, wrist turn, grip neutral
		     1500,1520,1500,1450, 1450,  // left hip, thigh,knee, foot roll, foot pitch
		        0,   0,   0,   0,        // reserved
                      1200, 1200,                // head nod, turn
		      1500,1450,1560,1200,1200,  // right shoulder, bicep,elbow,wrist turn, grip neutral
		      1450,1460,1500,1450,1500,  // right hip, thigh, knee, foot roll, foot pitch
		         0,   0,   0,   0,   0,  // reserved
                       0};            // reserved
float servosetup[32]= {1500,1450,1560, 1200, 1200, // left shoulder, bicep, elbow, wrist turn, grip neutral
		     1500,1520,1500,1450, 1450,  // left hip, thigh,knee, foot roll, foot pitch
		        0,   0,   0,   0,        // reserved
                      1200, 1200,                // head nod, turn
		      1500,1450,1560,1200,1200,  // right shoulder, bicep,elbow,wrist turn, grip neutral
		      1450,1460,1500,1450,1500,  // right hip, thigh, knee, foot roll, foot pitch
		         0,   0,   0,   0,   0,  // reserved
                       0};            // reserved
/********************************************************************
 ** servo movement limits in degrees mandated by hardware design
 *******************************************************************/
float servomin[32]={ 500, 600, 600, 500, 500, // left shoulder, bicep, elbow, wrist turn, grip neutral
                    1388, 600, 700,1338,1117, // left hip, thigh,knee, foot roll, foot pitch
                       0,   0,   0,   0,      // reserved
                     500, 500,                // head nod, turn
                     500, 500, 600, 500, 500, // right shoulder, bicep,elbow,wrist turn, grip neutral
                    1338, 700, 600, 1338,1117,// right hip, thigh, knee, foot roll, foot pitch
		      0,  0,  0,  0,  0,  0,  // reserved
			};

float servomax[32]={2500,2300,2400,2500,2500,    // left shoulder, bicep, elbow, wrist turn, grip neutral
                    1611,2200,2200,1560,1780,    // left hip, thigh,knee, foot roll, foot pitch
                      0,  0,  0,  0,  0,    // reserved
                    1700,2200,                // head nod, turn
                    2500,2300,2500,2500,2500,    // right shoulder, bicep,elbow,wrist turn, grip neutral
                    1500,2200,2200,1560,1780,    // right hip, thigh, knee, foot roll, foot pitch
		      0,  0,  0,  0,  0,  0,// reserved
			};
/********************************************************************
 ** a step is made by tilting the body over the opposing foot, then 
 ** moving the foot forward and the opposing arm reward to maintain balance
 ** The step is complete when the opposing foot is moved rearward, lowering
 ** forward foot to the ground. As the opposing foot pushes off, the opposing arm 
 ** swings forward to continue the balance, the two hips rotate, moving the center
 ** of the body over the current foot as the opposing knee lifts the opposing foot
 ** and brings it forward.  The step is completed when the opposing foot is parallel
 ** to the step foot and the next step can start, or the body can be brought upright
 ** and both feet planted for a stopped position.  Note that acceleration MUST be 
 ** controlled for the next position to continue smoothly.
 *********************************************************************/
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

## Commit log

2021-06-24 This is the initial print design
    [Base_AR2.stl, Claw.stl, Connector.stl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]
2021-06-25 added hs311library
    [HS311lib.scad]
2021-06-25 Added the top shoulderbearing and neck extension
    [shoulderbearing.scad]
2021-06-25 Code to drive the robot from the embedded raspberry pi using ssh over wifi
    The internal raspberry PI 4 8G uses a 128Gb flash card loaded with 2020-08-20-raspio-buster-full-arm.img. The user name is qubie, and you set a system name for your local network. These files load in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
    $ python3 robot.py
    Hold the robot up manually by the body so the feet are flat on a solid surface. Then hit return. The robot will stand.
    The face change code can run, but at this time has to be run separately afterr the robot is standing.
    python 3 facechange.py
2021-06-25 These stl files are for generating a gazebo simulation.
    Gazebo is scaled at meters, and stl is an unscaled format. You need to scale these to use them in gazebo. I am including a bit of C code called scalestl. Put that code where you can call it easily. In this directory issue the command:
    ls -alR * >temp.txt
    Then
    scaleSTL temp.txt
    The gazebo friendly stl files will be in a new subdirectory called STL
    [3218MainBracket.stl, ConGear.stl, DS3218.stl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]
2021-06-25 utility for scaling the STL files for Gazebo
2021-06-25 The ROS2 files for the qubie directory in qubie_ws/src
    Once you have created a qubie_ws directory on your ROS2 work computer for gazebo, go into the src directory and copy these files there. the final path should be /home/qubie/qubie_ws/src/qubie
    To use the models in gazebo log in as qubie. Then use the commands:
    cd qubie_ws
    . install/setup.bash
    gazebo
    ...... gazebo starts ......
    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
    [3218MainBracket.stl, ConGear.stl, DS3218.stl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]
2021-07-30 Add files via upload
    upgraded body required new wiring diagram. This is using fritzing to create that wiring diagram. More to come.
    [newbody07202021.fzz]
2021-08-10 updated this file to show the remaining connections
    Added the fan, connections to the 2.4 display for the face and some other connections and notes
    [newbody07202021.fzz]
